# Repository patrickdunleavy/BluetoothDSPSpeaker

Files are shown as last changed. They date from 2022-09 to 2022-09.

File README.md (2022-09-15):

# BluetoothDSPSpeaker  
Real-time DSP PCB backpack for an STM32F446 Nucleo breakout board

The goal of this project was to create a guitar pedal-like device for desktop speakers. Essentially, the pedal transforms any wired desktop speaker into a bluetooth speaker with extra on-board audio processing controls. The pedal uses a bluetooth audio reciever to send stereo audio signals through analog volume control, tone control, and a stereo codec for digital signal processing. 
  
**Analog:**  
* Board is powered with 9V and uses two voltage regulators to achieve 5V and 3V3  
* NE5532 Op-amps chosen because of low noise, higher current capabilites and popularity in the audio industry  
* Op-amps were supplied with a single 5V rail, meaning every op-amp was biased with 2.5V to achieve maximum end-to-end amplification  
* Voltage followers used to establish 2.5V bias voltages for the left and right channels individually  
* Baxandall volume control used to achieve a logarithmic volume response while using a linear dual-gang potentiometer for control  
* Bass and treble control achieved through first-order filters and dual-gang potentiometers  
* Another potentiometer used for the ADC hardware on the digital end  
* Bluetooth reciever interfaced with resistors and buttons to allow the user to access the previous song, next song, and pause the song from on the board itself  
* Bypass caps for every IC, microcontroller power pins, and the codec  

**Digital:**  
* STM32F446x ARM microprocessor used along with the STM32 Cube IDE for HAL layer functions  
* I2C driver written for the TLV320AIC23B Stereo Audio Codec  
* I2S used to receive and transmit data between the microcontroller and the codec  
* DMA and ping pong buffers used to offload calculations from the microcontroller  
* Reverb filter implemented with parameters varying based on ADC values  

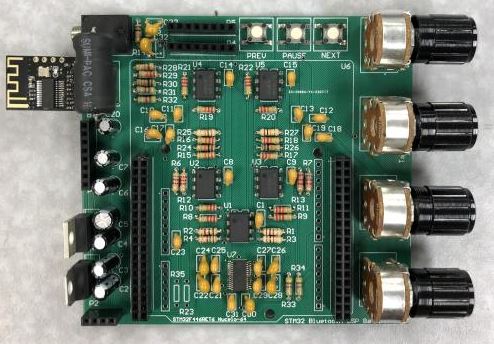
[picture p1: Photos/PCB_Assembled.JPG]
Assembled PCB ASse PCB
  
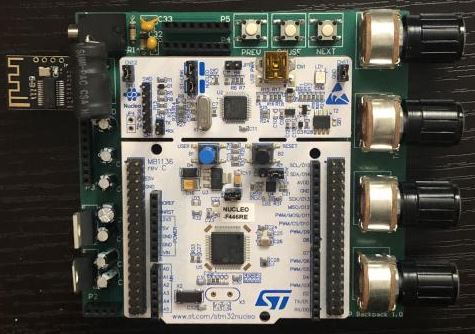
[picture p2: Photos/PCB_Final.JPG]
Complete PCB
  
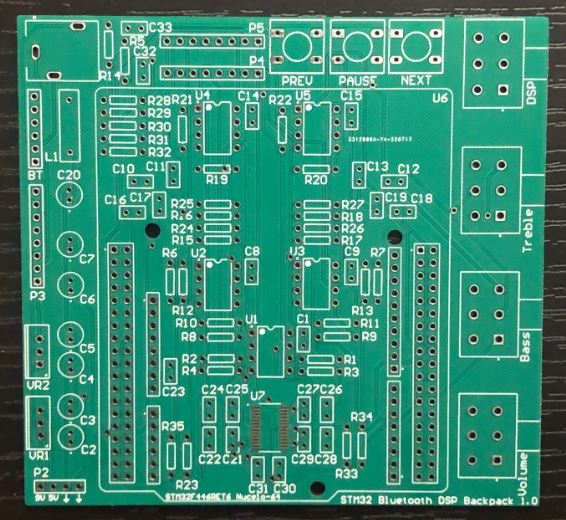
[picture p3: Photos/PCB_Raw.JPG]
Empty PCB


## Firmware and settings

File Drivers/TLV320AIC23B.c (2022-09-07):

/*
 * TLV320AIC23B Stereo Audio CODEC I2C Driver
 *
 * Patrick Dunleavy | 7/13/2022
 *
 */
#include "TLV320AIC23B.h"


void TLV320AIC23B_init(TLV320AIC23B *dev, I2C_HandleTypeDef *i2cHandle)
{
	// Struct Parameters
	dev->i2cHandle = i2cHandle;
	// Reset Codec
	TLV320AIC23B_write(dev, TLV320AIC23B_I2C_ADDR_0, TLV320AIC23B_REG_RESET, 0x0000);
	// Power Control | Turn Mic input off
	TLV320AIC23B_write(dev, TLV320AIC23B_I2C_ADDR_0, TLV320AIC23B_REG_PWRDOWN_CTRL, 0x0002);
	// Digital Interface | Slave mode, DAC L/R Swap off, I2S timing, 16 bit input length, I2S data format
	TLV320AIC23B_write(dev, TLV320AIC23B_I2C_ADDR_0, TLV320AIC23B_REG_DIGI_INTERFACE_FORMAT, 0x0012);
	// Left Input Line Volume | L/R Simultaneous volume update, 0dB input gain
	TLV320AIC23B_write(dev, TLV320AIC23B_I2C_ADDR_0, TLV320AIC23B_REG_LLINE_VOLCTRL, 0x0097);
	// Right Input Line Volume | R/L Simultaneous volume update, 0dB input gain
	TLV320AIC23B_write(dev, TLV320AIC23B_I2C_ADDR_0, TLV320AIC23B_REG_RLINE_VOLCTRL, 0x0097);
	// Analog Audio Path | DAC SELECT???, No bypass, Line input for ADC, Mic mute
	TLV320AIC23B_write(dev, TLV320AIC23B_I2C_ADDR_0, TLV320AIC23B_REG_ANALOG_PATHCTRL, 0x0012);
	// Digital Audio Path
	TLV320AIC23B_write(dev, TLV320AIC23B_I2C_ADDR_0, TLV320AIC23B_REG_DIGI_PATHCTRL, 0x0000);
	// Sample Rate | 48 kHz, USB mode (12 MHz clock)
	TLV320AIC23B_write(dev, TLV320AIC23B_I2C_ADDR_0, TLV320AIC23B_REG_SAMP_RATE_CTRL, 0x0001);
	// Activating Digital Interface
	TLV320AIC23B_write(dev, TLV320AIC23B_I2C_ADDR_0, TLV320AIC23B_REG_DIGI_INTERFACE_ACTIV, 0x0001);

}
void TLV320AIC23B_write(TLV320AIC23B *dev, uint8_t address, uint8_t reg, uint16_t data)
{

	uint8_t dataH = data >> 8;
	uint8_t dataL = (uint8_t) (data & 0x00FF);

	// HAL_I2C_Mem_Write(hi2c, DevAddress, MemAddress, MemAddSize, pData, Size, Timeout)
	HAL_I2C_Mem_Write(dev->i2cHandle, address, ((reg<<1) | dataH), 1, &dataL, 1, 50);
}
